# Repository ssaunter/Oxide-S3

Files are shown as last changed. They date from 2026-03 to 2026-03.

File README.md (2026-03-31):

# Oxide-S3
Oxide-S3 is a retro Spotify interface featuring a large TFT screen, a small OLED screen, 6 tactile switches, and 2 rotary encoders, all running on an ESP32-WROOM-1.

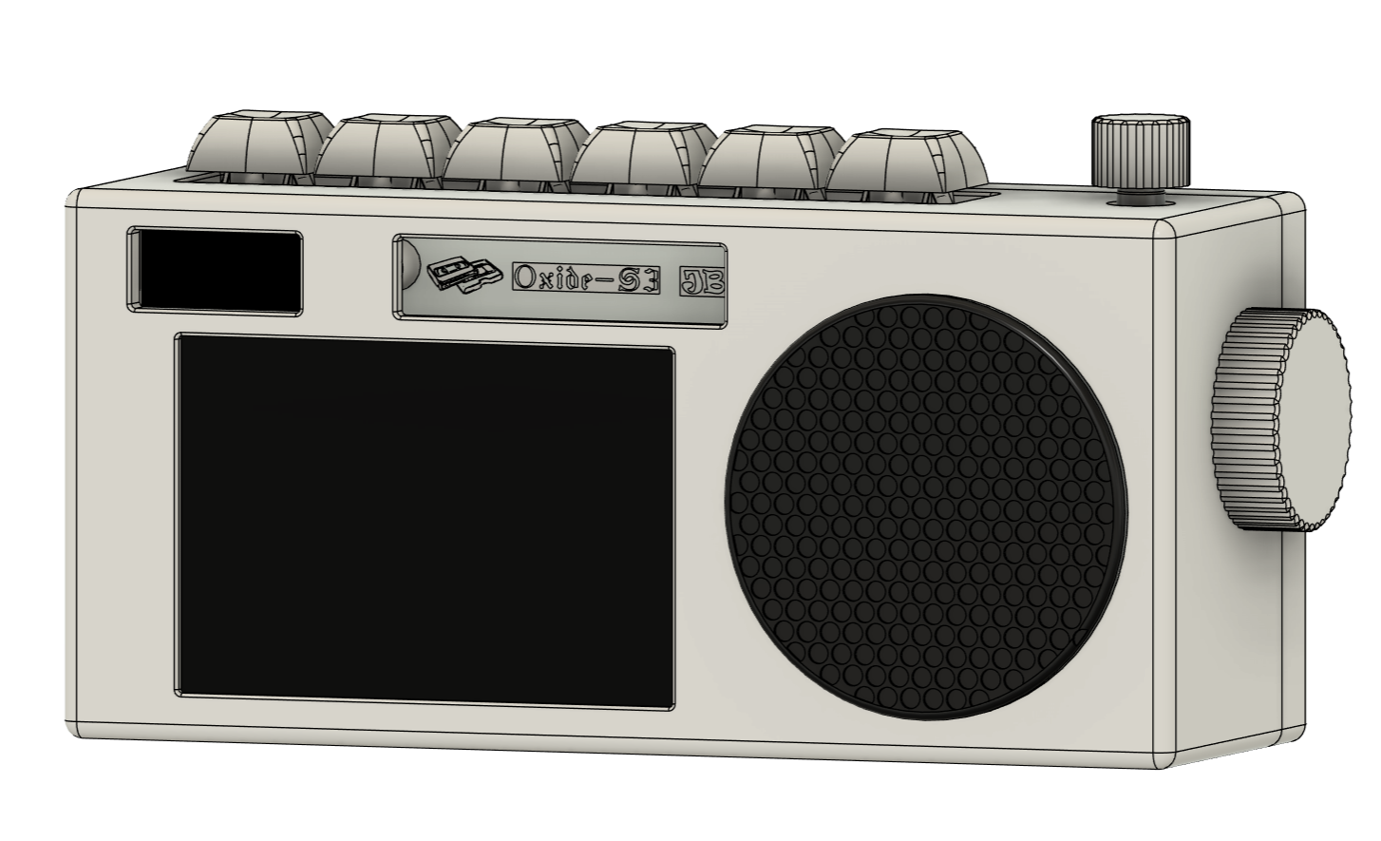
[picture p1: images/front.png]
Front Device


The device uses three seperate PCBs, one for the front, one for the top, and one for the side. The front PCB includes the displays, LiPo battery management, the MCU, and USB-C for charging. The top PCB includes the 6 Cherry MX Blue switches, and one of the rotary encoders. The side PCB simply includes the final rotary encoder. The small PCBs are connected to the front PCB using JST-XH cables.

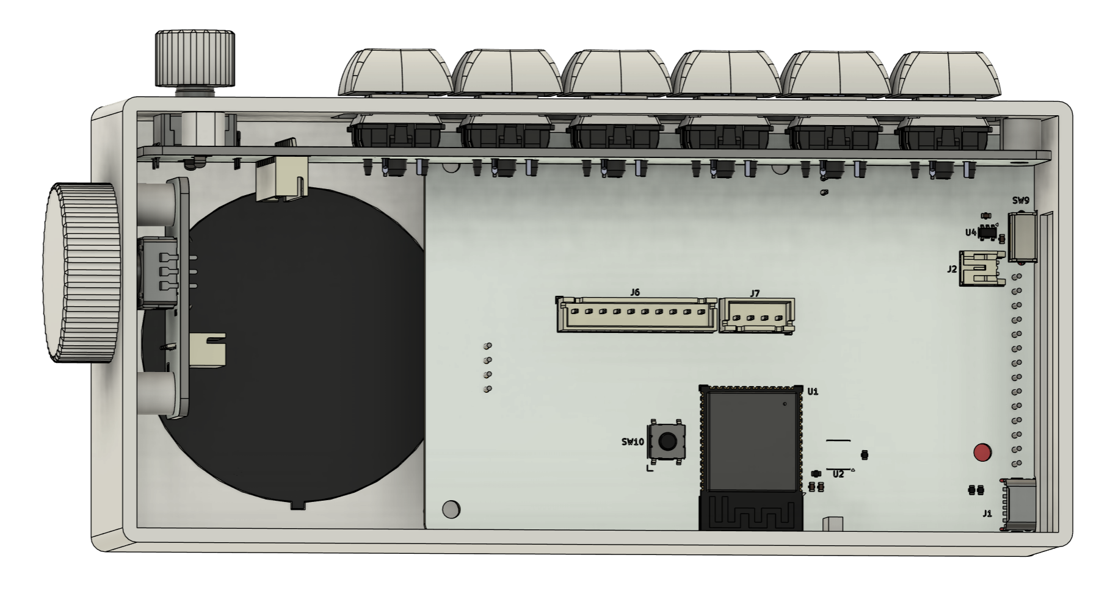
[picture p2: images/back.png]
Back Device


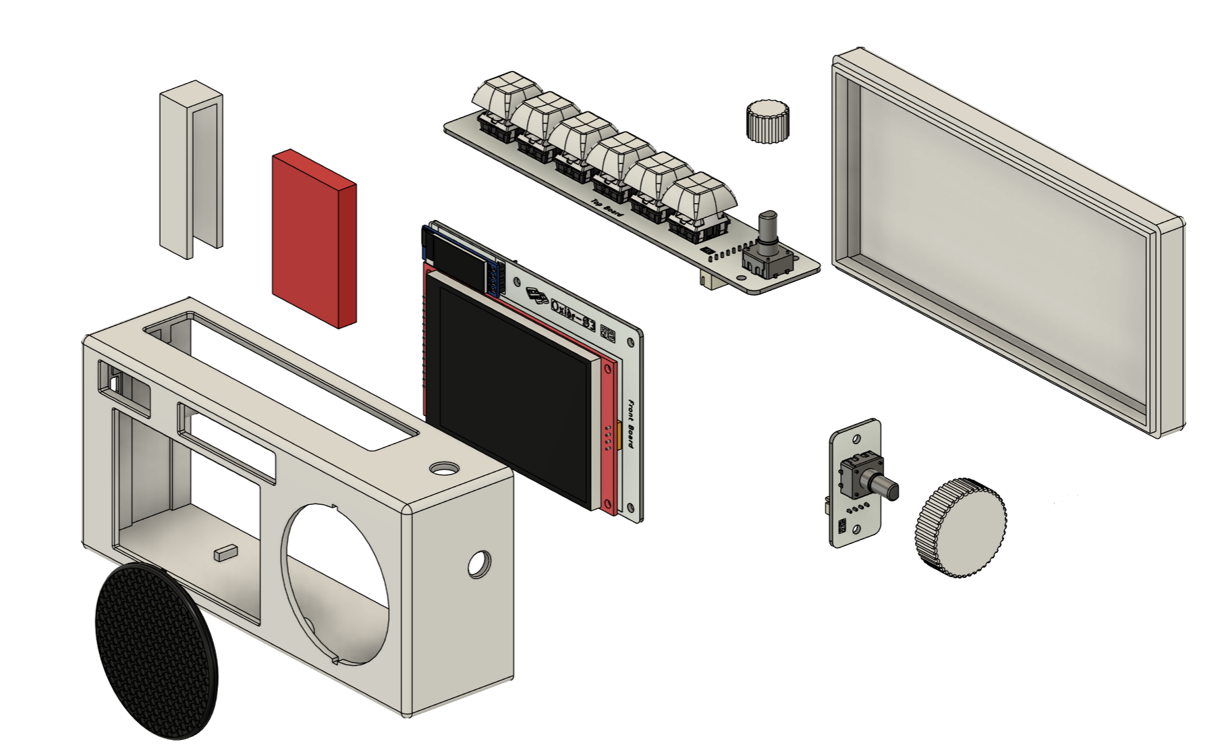
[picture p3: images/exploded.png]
Exploded View


# The PCBs

Front PCB:

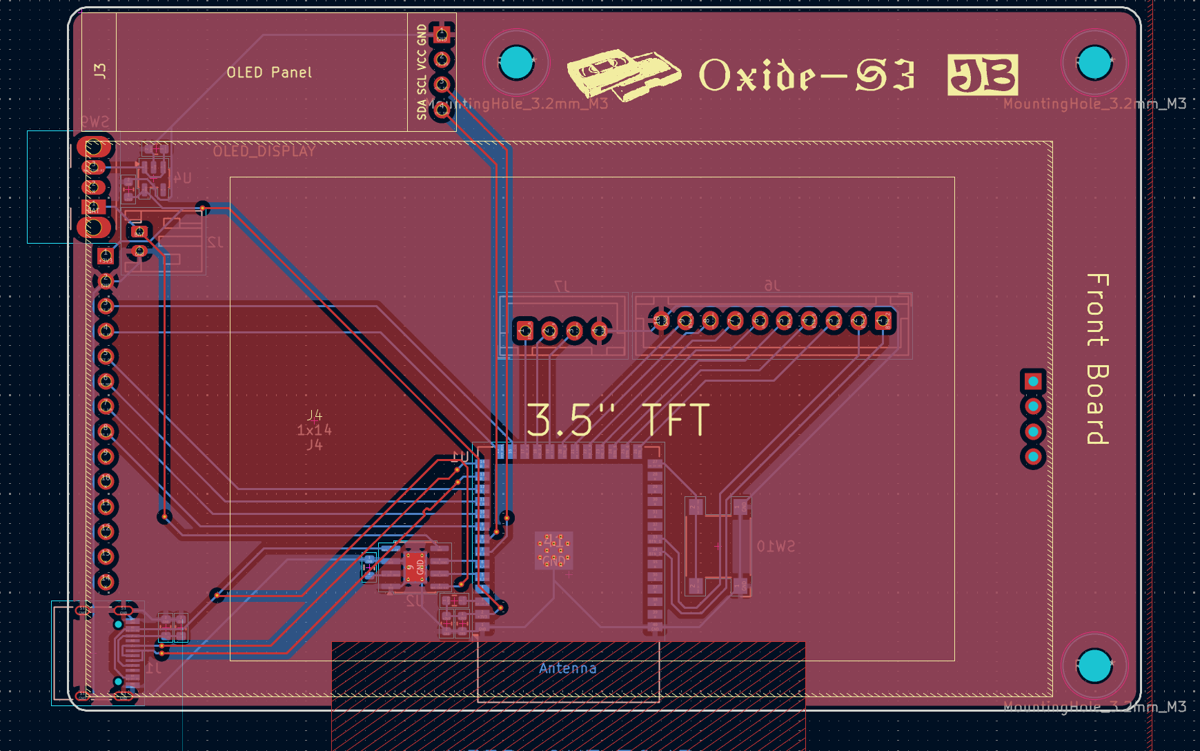
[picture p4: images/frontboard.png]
Front PCB


Top PCB:

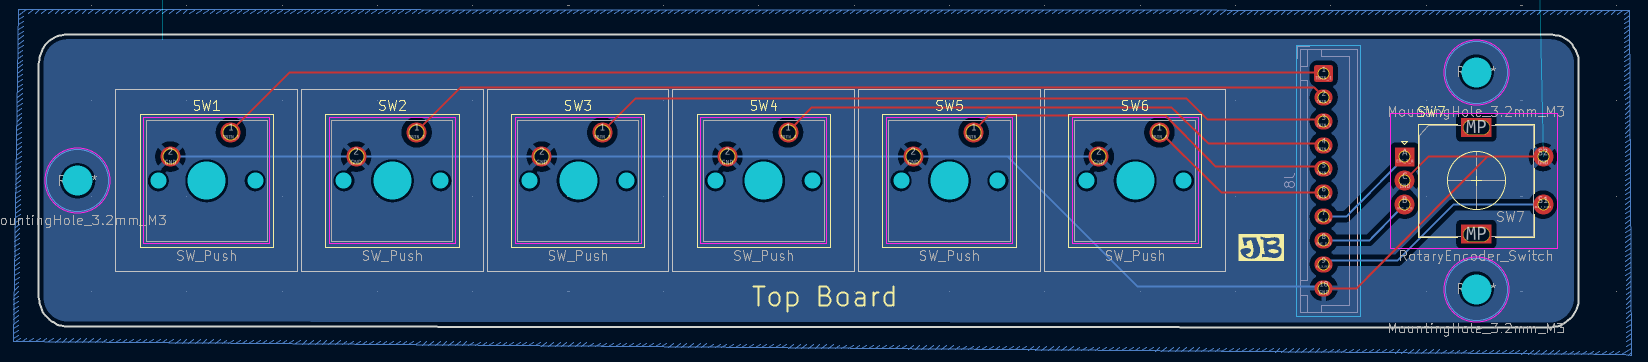
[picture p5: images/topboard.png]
Top PCB


Side PCB:

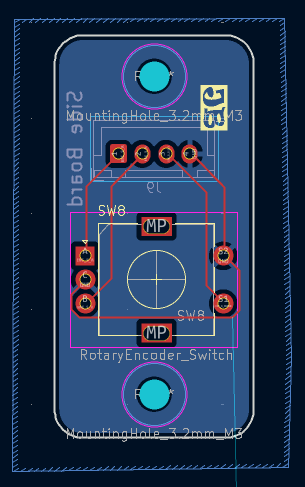
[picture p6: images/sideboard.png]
Side PCB


Schematic:

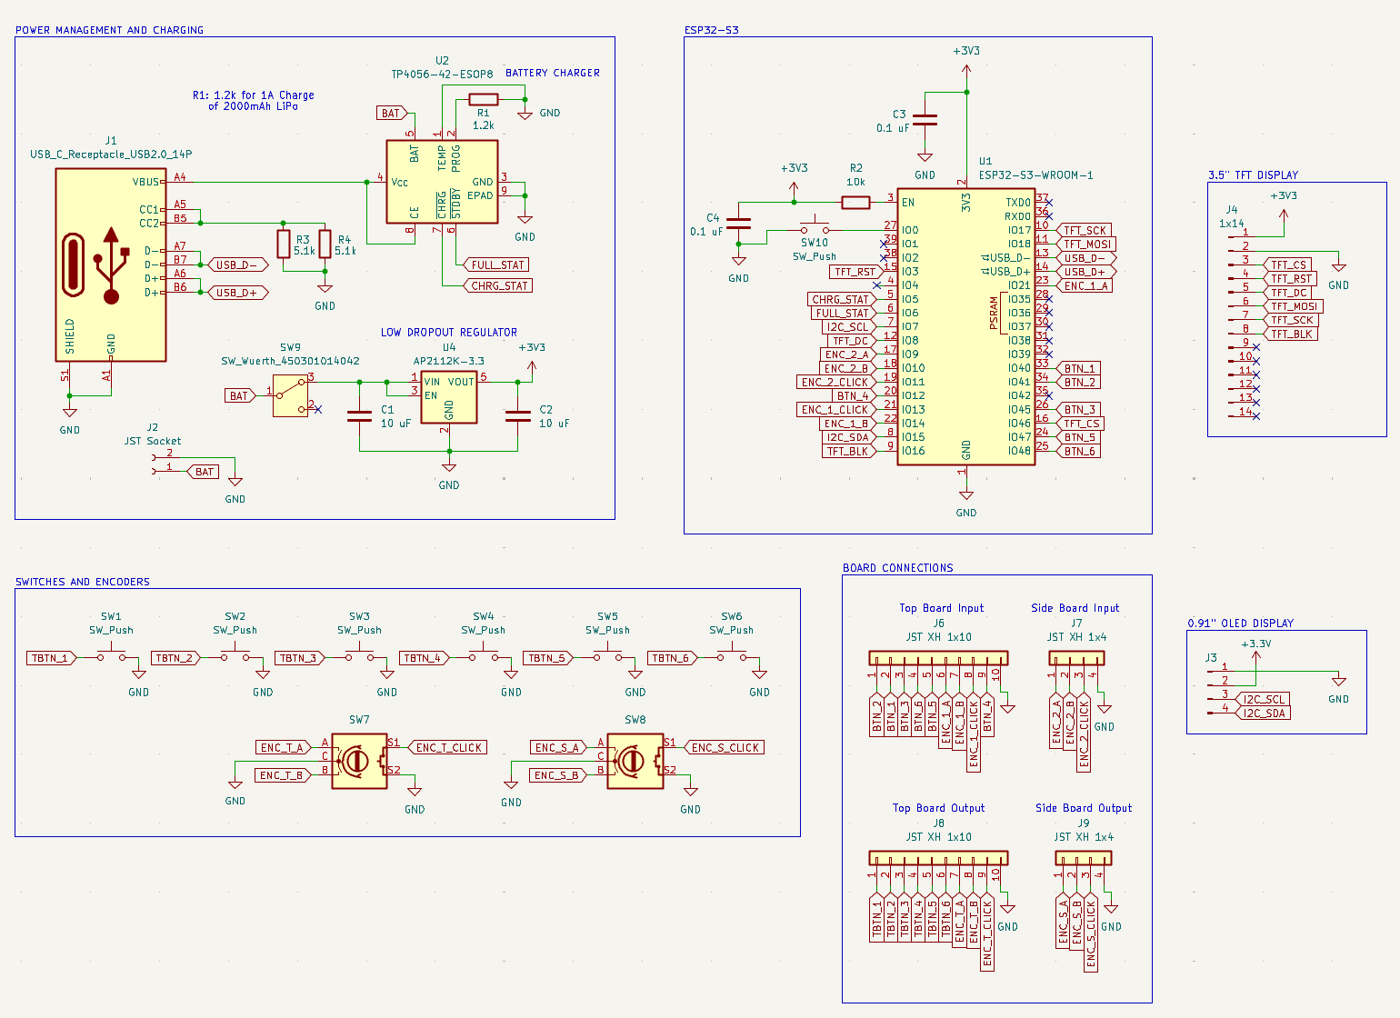
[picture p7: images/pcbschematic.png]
Schematic


# Assembly

The assembly is performed in several steps. First, 8 M3x5x5 threaded inserts are installed to the standoffs in the 3D printed front case. Then, the three PCBs are secured using M3x6 bolts.

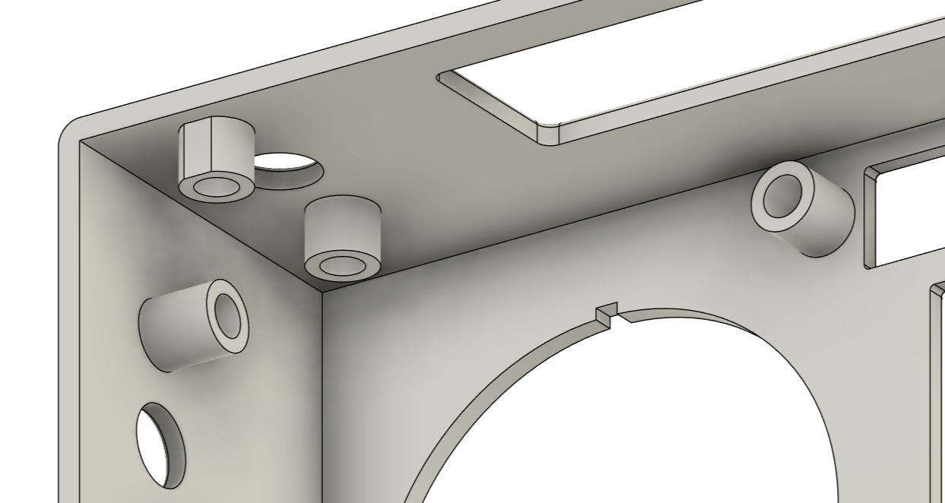
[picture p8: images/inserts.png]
Standoffs


 After the PCBs are installed, the battery holder module is press-fit into the front case, and the LiPo battery (red) is slid into place.

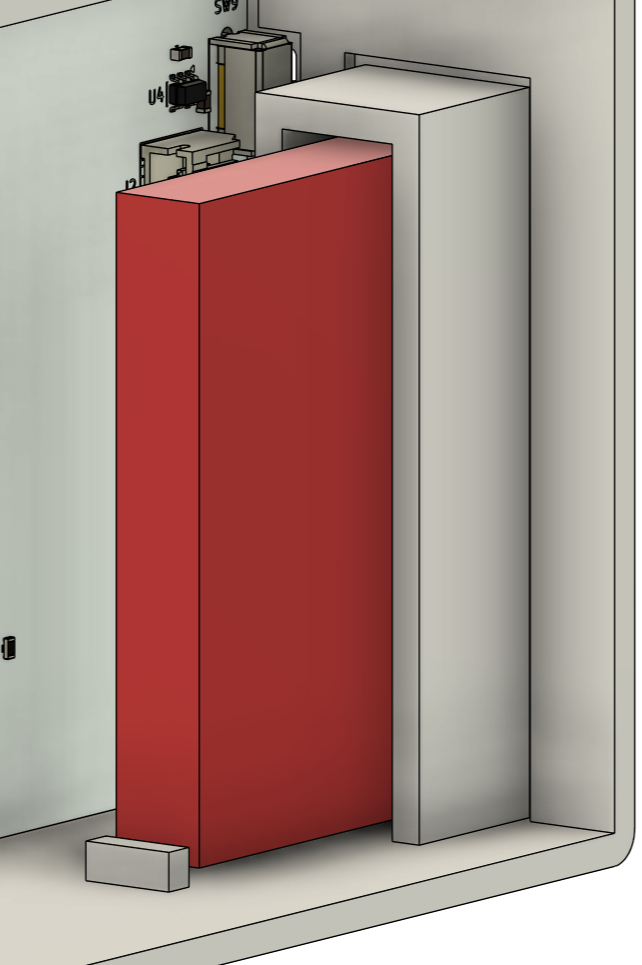
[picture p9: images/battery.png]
Battery


Then, the speaker and back case are press-fit into place. There is a 0.2mm tolerance built into the CAD model. 

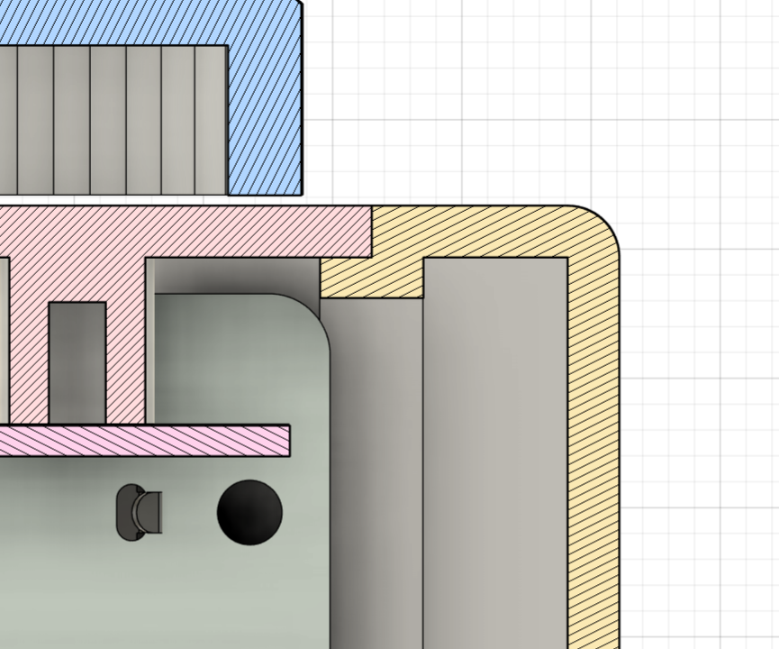
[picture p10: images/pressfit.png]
Press Fit


Finally, the side and top knob are  press-fit onto the rotary encoders. This concludes the assembly.

# Software

Taking inspiration from [Donatnan Jong](https://github.com/Dongathan-Jong), I plan to utilize Spotify's built-in [developer interface](https://developer.spotify.com/) and Adafruit display libraries to program the screens in the Arduino IDE. Since Wifi is easily handled by the ESP32 and the switches handled by Spotify's interface, the main focus would be on managing the displays. Given my short project turnaround time, I will update this repo once parts arrive.

The TFT screen will be controlled through SPI, and the OLED through I2C. To add images, I'll use a bitmap tool to add features. Below are the major functions of the two displays:

Required Libraries:
---
```
#include <Arduino.h>
#include <ArduinoJson.h>
#include <Adafruit_GFX.h>
#include <Adafruit_ST7735.h>
#include <WiFi.h>
#include <SpotifyEsp32.h>
#include <SPI.h>
```

|3.5" TFT|
| :---: |
|Spotify symbol|
|Song timestamp|
|Audio wave animation|
|Key switch/encoder map|
|Album navigation|
|Spotify username|

|0.91" OLED|
| :---: |
|Battery charge status|
|Clock|
|Volume/Mute symbol|
|Wifi status|

Like I mentioned, this project is super last minute (started less than a day ago). I'll write the code and update this repo once I recieve the parts, and show off what the Oxide-S3 can do. Here's an example of how simple the code can be, written by [Donatnan Jong](https://github.com/Dongathan-Jong/SpotifyDisplay/?tab=readme-ov-file):

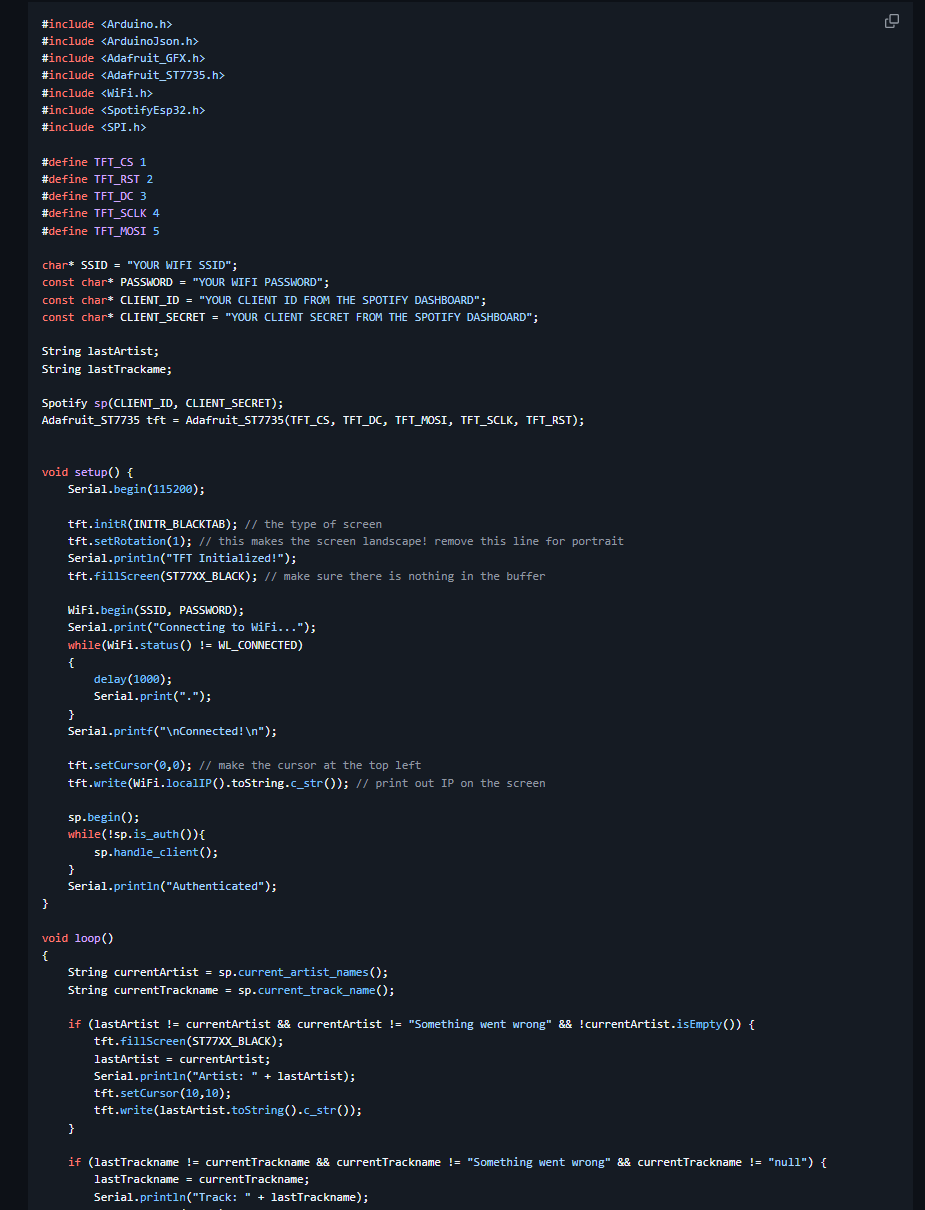
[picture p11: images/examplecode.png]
Example Code


# BOM

| Part | Quantity | Price Per | Link | 
| :--- | :---: | :---: | :--- |
| **0.91" OLED** | 1 | $1.95 | [AliExpress](https://www.aliexpress.us/item/3256806449757543.html) |
| **3.5" TFT** | 1 | $10.45 | [AliExpress](https://www.aliexpress.us/item/3256801812264108.html) |  
| **ESP32-S3-WROOM-1-N8R8** | 1 | $6.13 | [DigiKey](https://www.digikey.com/short/wq4p3rwv) |
| **LDO** | 1 | $0.22 | [DigiKey](https://www.digikey.com/short/b2m9hq2c) |
| **Battery Charger** | 1 | $0.47 | [DigiKey](https://www.digikey.com/short/dz9hbfw5) |
| **USB-C Recepticle** | 1 | $0.78 | [DigiKey](https://www.digikey.com/short/rnhfh9zp) |
| **Rotary Encoder** | 2 | $1.72 | [DigiKey](https://www.digikey.com/short/1mq4zdpt) |
| **Boot Button** | 1 | $0.56 |[DigiKey](https://www.digikey.com/short/q5bt28qt) |
| **Slide Switch** | 1 | $0.65 | [DigiKey](https://www.digikey.com/short/41mc094h) |
| **1x2 JST-PH** | 1 | $0.11 | [DigiKey](https://www.digikey.com/short/41b2w40z) |
| **1x10 JST-XH** | 2 | $0.32 |[DigiKey](https://www.digikey.com/short/5571c5z5) |
| **1x4 JST-XH** | 2 | $0.14 | [DigiKey](https://www.digikey.com/short/h5trn14w) |
| **1.2k R 0603** | 1 | $0.10 |[DigiKey](https://www.digikey.com/short/hnr0jfrp) |
| **5.1k R 0603** | 2 | $0.10 |[DigiKey](https://www.digikey.com/short/mmd3843z) |
| **10k R 0603** | 1 | $0.10 | [DigiKey](https://www.digikey.com/short/p59dnbn3) |
| **0.1uF C 0603** | 2 | $0.12 |[DigiKey](https://www.digikey.com.au/short/w83wjqbv) |
| **10uF C 0603** | 2 | $0.35 |[DigiKey](https://www.digikey.com/short/5dtppp4z) |
| **DSA Keycaps 10pcs** | 1 | (have) |[DigiKey](https://www.digikey.com/short/p4j0ztf5) |
| **Cherry MX Blue 10pcs** | 1 | $4.00 |[MechanicalKeyboards](https://mechanicalkeyboards.com/products/cherry-mx-blue-60g-clicky) |
| **1x10 JST-XH Jumper** | 1 | $3.40 |[AliExpress](https://www.aliexpress.us/item/3256807069159656.html) |
| **1x4 JST-XH Jumper** | 1 | $2.36 |[AliExpress](https://www.aliexpress.us/item/3256807069159656.html) |
| **1S 1500mAh LiPo** | 1 | (have) |[SparkFun](https://www.sparkfun.com/lithium-ion-battery-1500mah-iec62133-certified.html#content-documentation) |
| **MicroSD** | 1 | (have) | |
| **M3x6 Bolt** | 8 | (have) | |
| **M3x5x5 Threaded Insert** | 8 | (have) | |

Totals
---
| Service  | Price | 
| :--- | :--- |
| **JLCPCB Order** | $48.49 | |
| **DigiKey Order** | $32.36 | 
| **AliExpress Order** |  $19.44 | 
| **MechanicalKeyboards Order** |  $9.52 | 

This total comes out to $109.81 which is slightly over my limit. I'll downgrade to some generic Cherry MX Red switches, and some old DSA switches, both which I alreday have bringing the total to **$94.34**.

Orders:

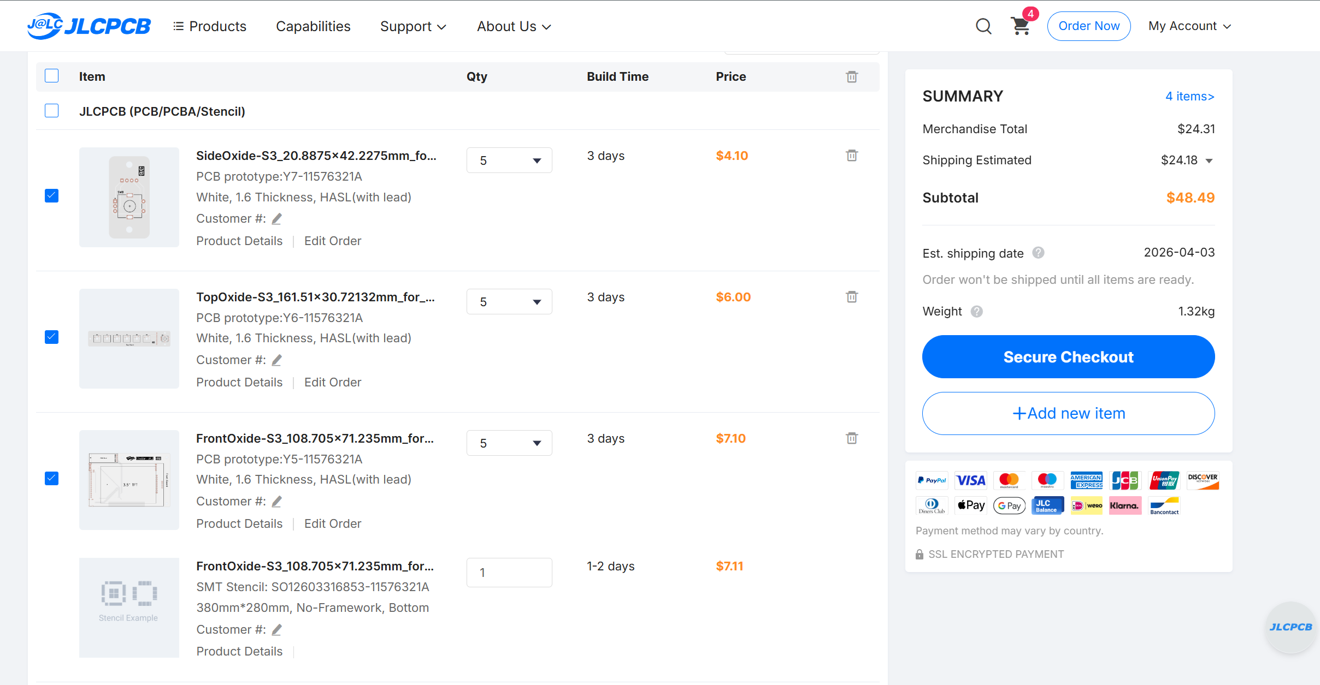
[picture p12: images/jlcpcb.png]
JLCPCB

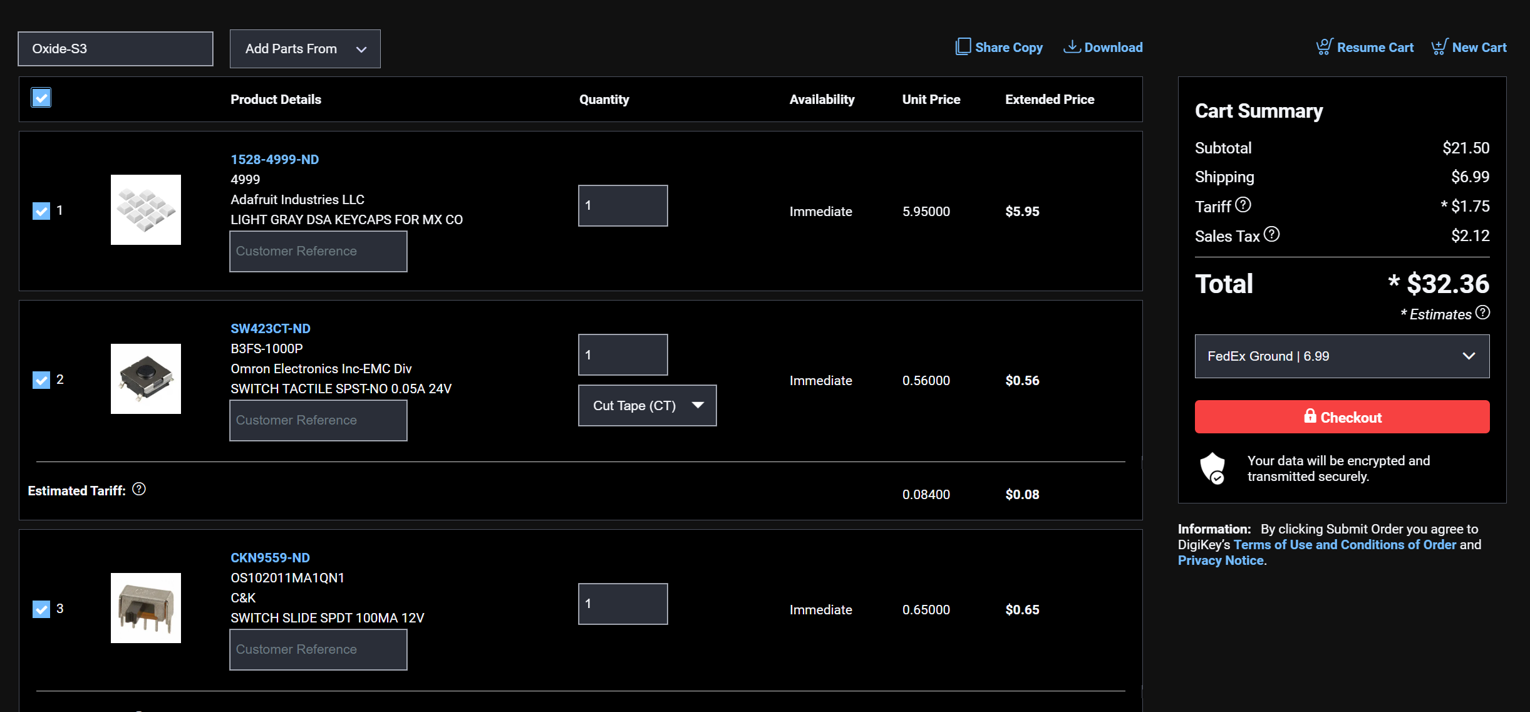
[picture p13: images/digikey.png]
Digikey

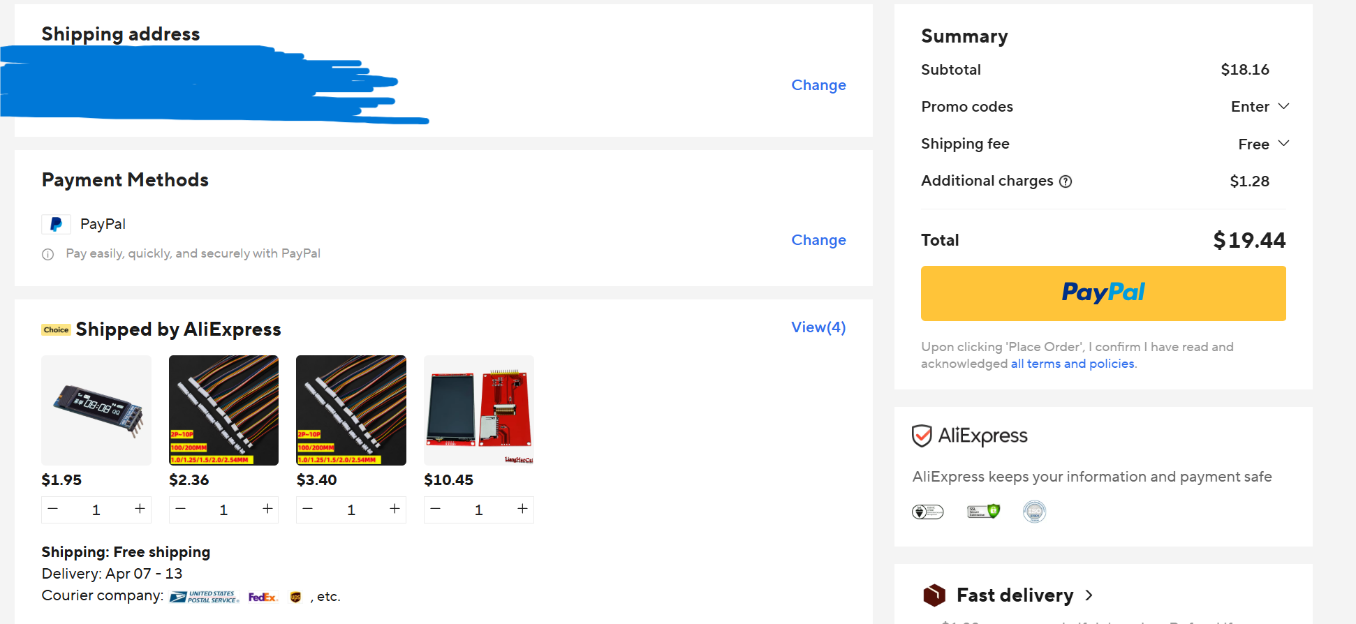
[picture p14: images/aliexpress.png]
AliExpress

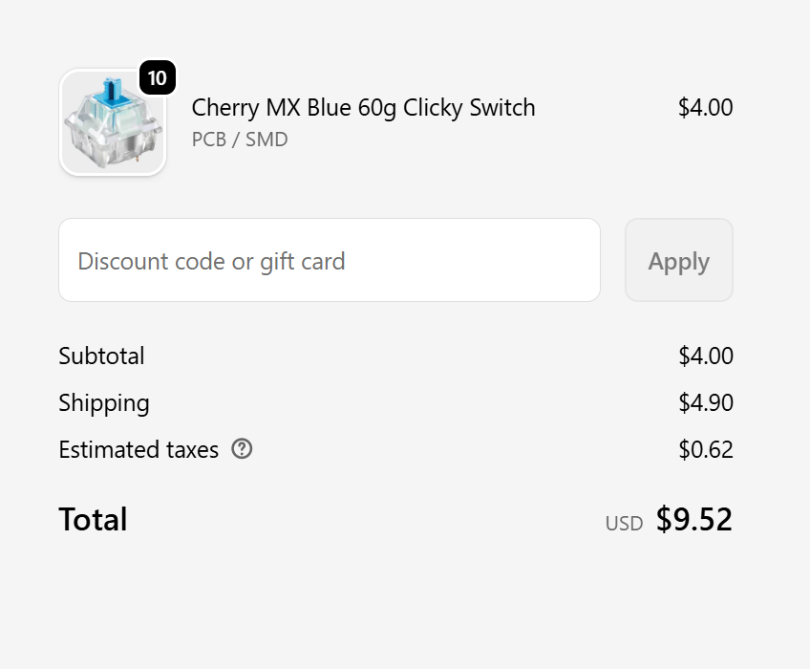
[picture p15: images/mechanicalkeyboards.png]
MechanicalKeyboards


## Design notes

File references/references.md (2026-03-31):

# Project References

[Dongathan-Jong Spotify Display](https://github.com/Dongathan-Jong/SpotifyDisplay/?tab=readme-ov-file)

Spotify Display

Old Radio

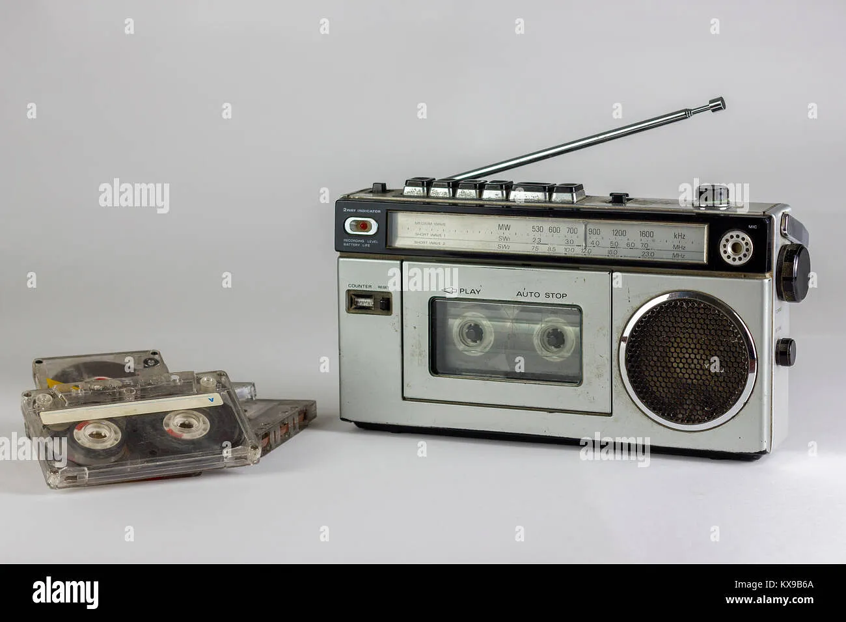
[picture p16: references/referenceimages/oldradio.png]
Old Radio


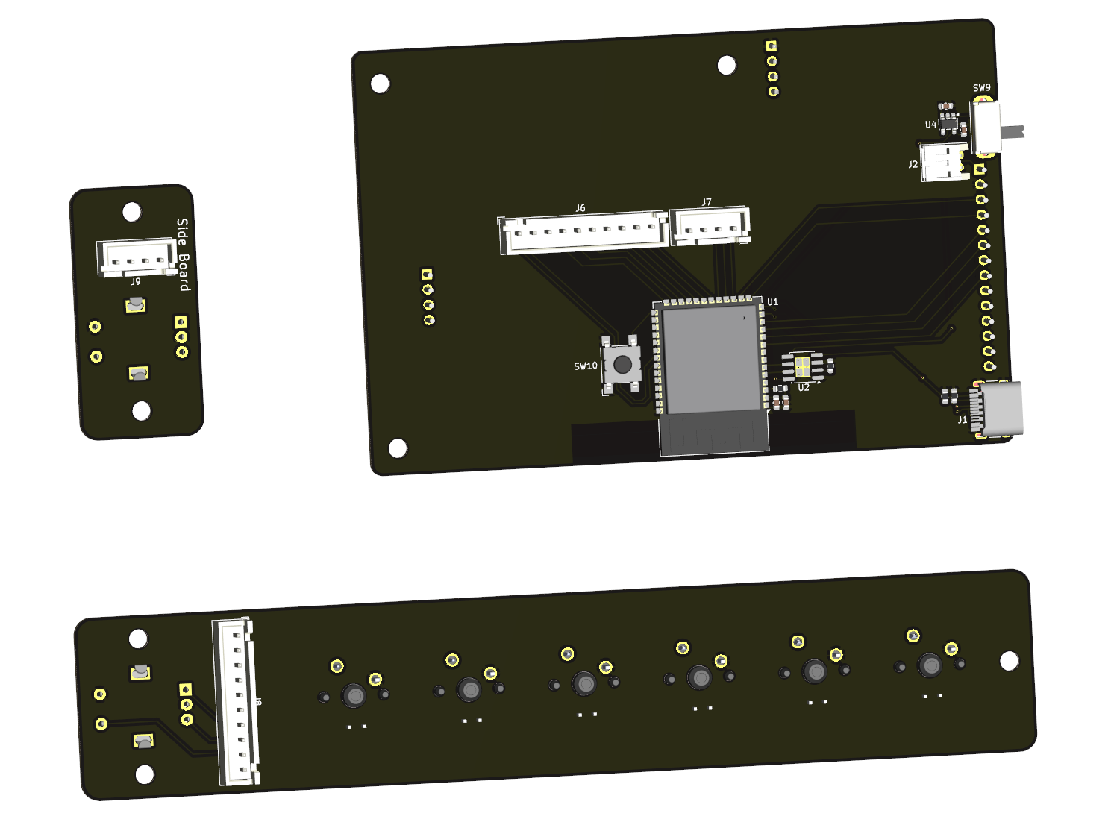
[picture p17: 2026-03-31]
images/3dpcbback.png

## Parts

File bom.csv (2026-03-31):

Part | Quantity | Price Per | Link
0.91-inch OLED | 1 | 1.95 | https://www.aliexpress.us/item/3256806449757543.html
3.5-inch TFT | 1 | 10.45 | https://www.aliexpress.us/item/3256801812264108.html
ESP32-S3-WROOM-1-N8R8 | 1 | 6.13 | https://www.digikey.com/short/wq4p3rwv
LDO | 1 | 0.22 | https://www.digikey.com/short/b2m9hq2c
Battery Charger | 1 | 0.47 | https://www.digikey.com/short/dz9hbfw5
USB-C Recepticle | 1 | 0.78 | https://www.digikey.com/short/rnhfh9zp
Rotary Encoder | 2 | 1.72 | https://www.digikey.com/short/1mq4zdpt
Boot Button | 1 | 0.56 | https://www.digikey.com/short/q5bt28qt
Slide Switch | 1 | 0.65 | https://www.digikey.com/short/41mc094h
1x2 JST-PH | 1 | 0.11 | https://www.digikey.com/short/41b2w40z
1x10 JST-XH | 2 | 0.32 | https://www.digikey.com/short/5571c5z5
1x4 JST-XH | 2 | 0.14 | https://www.digikey.com/short/h5trn14w
1.2k R 0603 | 1 | 0.10 | https://www.digikey.com/short/hnr0jfrp
5.1k R 0603 | 2 | 0.10 | https://www.digikey.com/short/mmd3843z
10k R 0603 | 1 | 0.10 | https://www.digikey.com/short/p59dnbn3
0.1uF C 0603 | 2 | 0.12 | https://www.digikey.com.au/short/w83wjqbv
10uF C 0603 | 2 | 0.35 | https://www.digikey.com/short/5dtppp4z
DSA Keycaps 10pcs | 1 | Handled | https://www.digikey.com/short/p4j0ztf5
1x10 JST-XH Jumper | 1 | 3.40 | https://www.aliexpress.us/item/3256807069159656.html
1x4 JST-XH Jumper | 1 | 2.36 | https://www.aliexpress.us/item/3256807069159656.html
1S 1500mAh LiPo | 1 | Handled | https://www.sparkfun.com/lithium-ion-battery-1500mah-iec62133-certified.html
MicroSD | 1 | Handled
M3x6 Bolt | 8 | Handled
M3x5x5 Threaded Insert | 8 | Handled
Generic MX Red Switches | 6 | Handled
Service | Price
JLCPCB Order | 48.49
DigiKey Order | 26.41
AliExpress Order | 19.44
TOTAL | 94.34

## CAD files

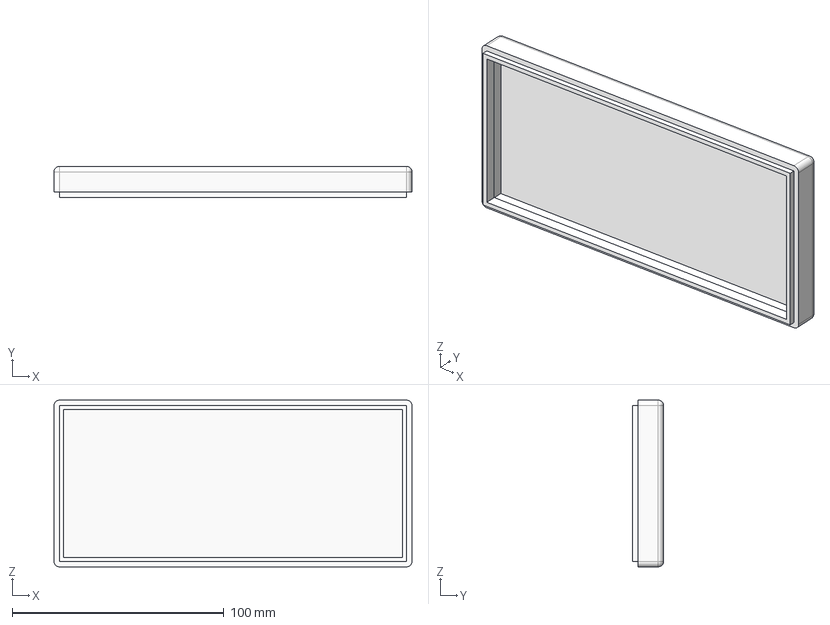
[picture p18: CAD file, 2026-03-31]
cad/Back Case.step
169.1 x 14.7 x 78.7 mm

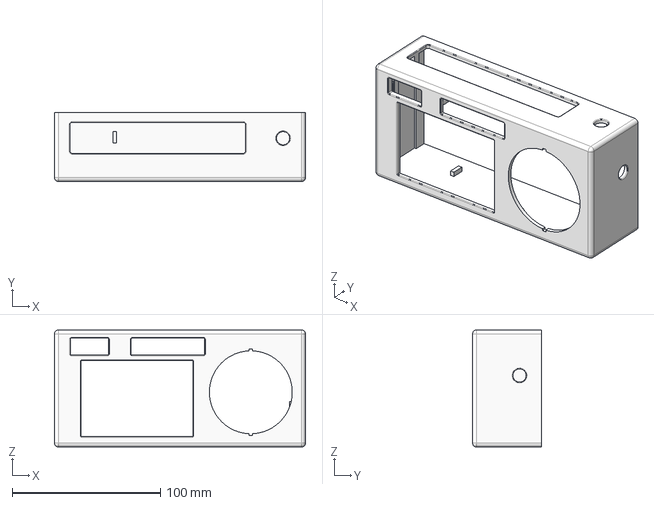
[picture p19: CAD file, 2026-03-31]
cad/Front Case.step
169.1 x 46.4 x 78.7 mm

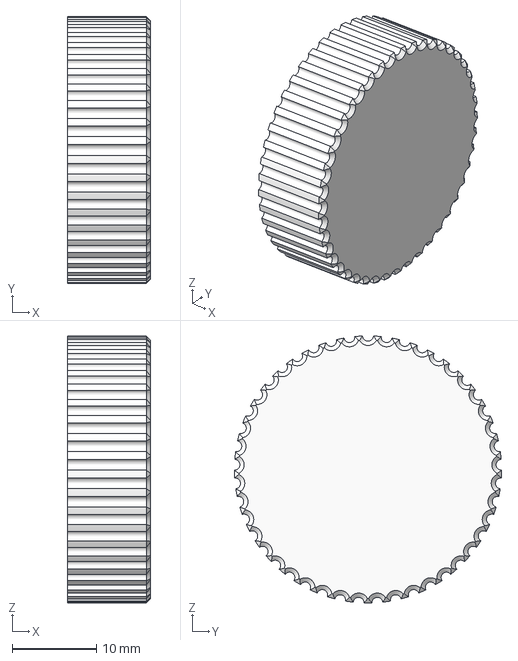
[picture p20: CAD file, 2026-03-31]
cad/Side Dial.step
9.91 x 31.7 x 31.7 mm

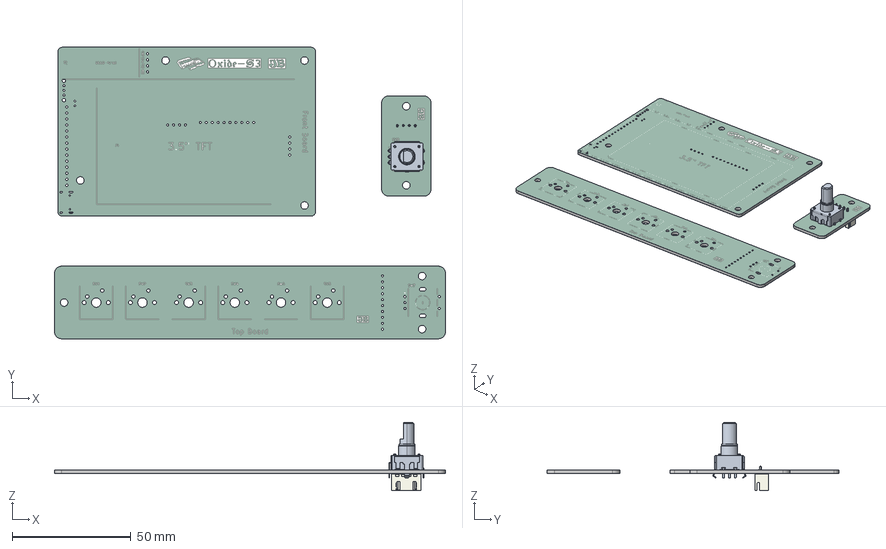
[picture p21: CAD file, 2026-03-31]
cad/Oxide-S3SIDE.step
164.8 x 122.9 x 28.7 mm
pec12r-4225f-s0024
JST_XH_B4B-XH-A_1x04_P2.50mm_Vertical
Oxide-S3_silkscreen x 2
Oxide-S3_soldermask x 2
Oxide-S3_PCB_1
Oxide-S3_PCB_2
Oxide-S3_PCB_3

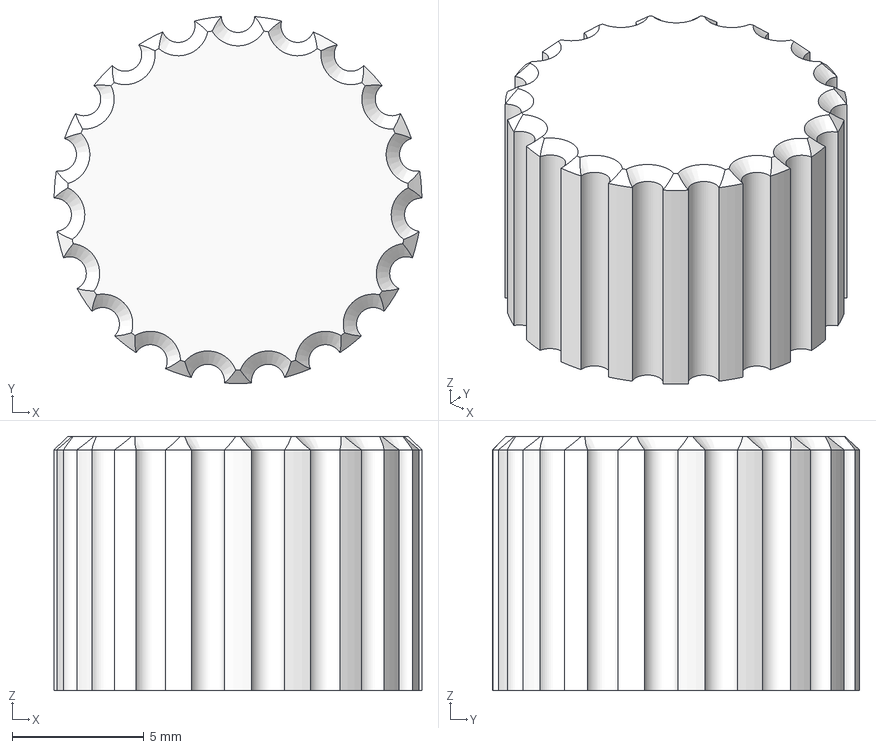
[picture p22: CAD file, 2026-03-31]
cad/Top Dial.step
14.0 x 13.9 x 9.65 mm

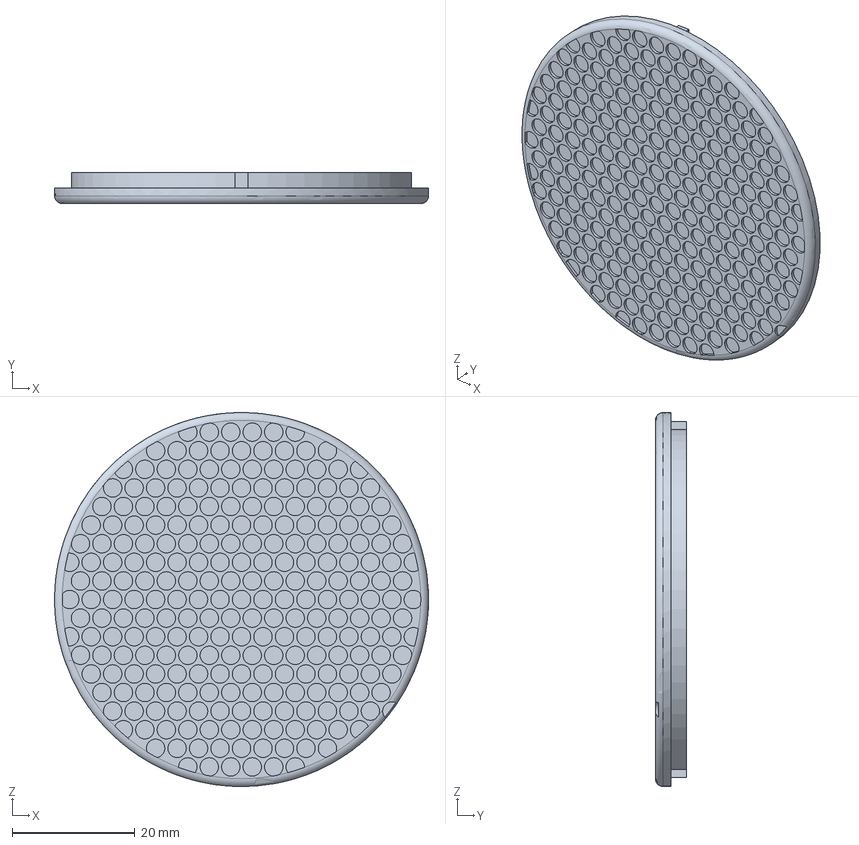
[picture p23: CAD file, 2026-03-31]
cad/Speaker Plate.step
60.9 x 5.08 x 61.0 mm

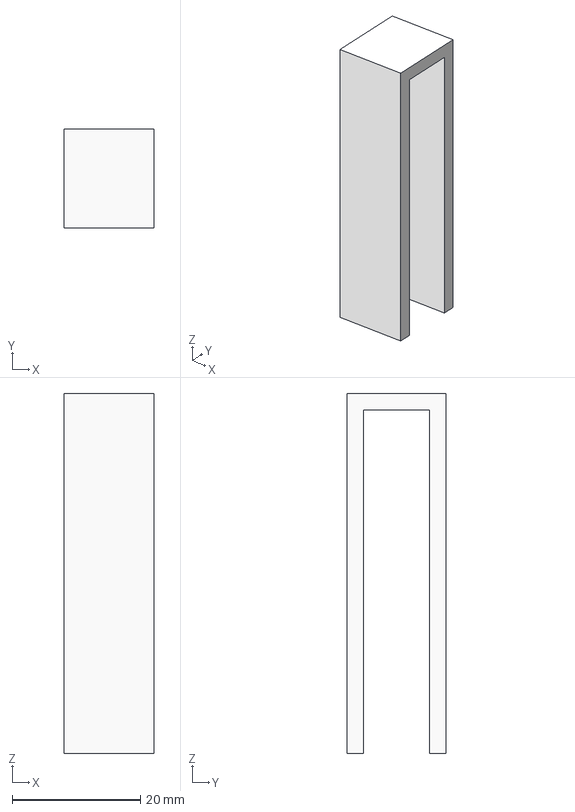
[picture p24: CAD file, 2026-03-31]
cad/Battery Holder.step
14.0 x 15.4 x 56.1 mm

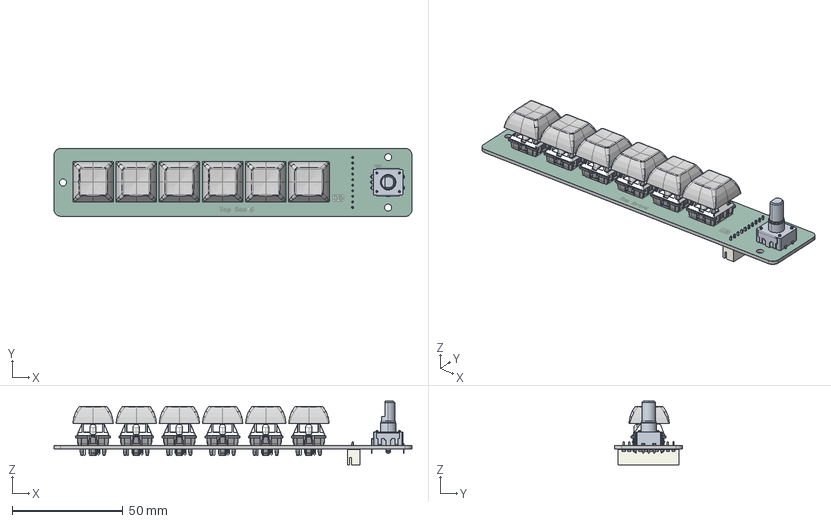
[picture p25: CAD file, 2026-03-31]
cad/Oxide-S3TOP.step
161.5 x 30.7 x 28.7 mm
Bottom x 6
Pulsador x 6
Top x 6
Pieza5^Cherry MX x 6
Pin1 x 6
Pin2 x 6
Led 3mm_trans x 6
DSA_Keycap_CherryMX x 6
pec12r-4225f-s0024
JST_XH_B10B-XH-A_1x10_P2.50mm_Vertical
Oxide-S3_silkscreen x 2
Oxide-S3_soldermask x 2
Oxide-S3_PCB

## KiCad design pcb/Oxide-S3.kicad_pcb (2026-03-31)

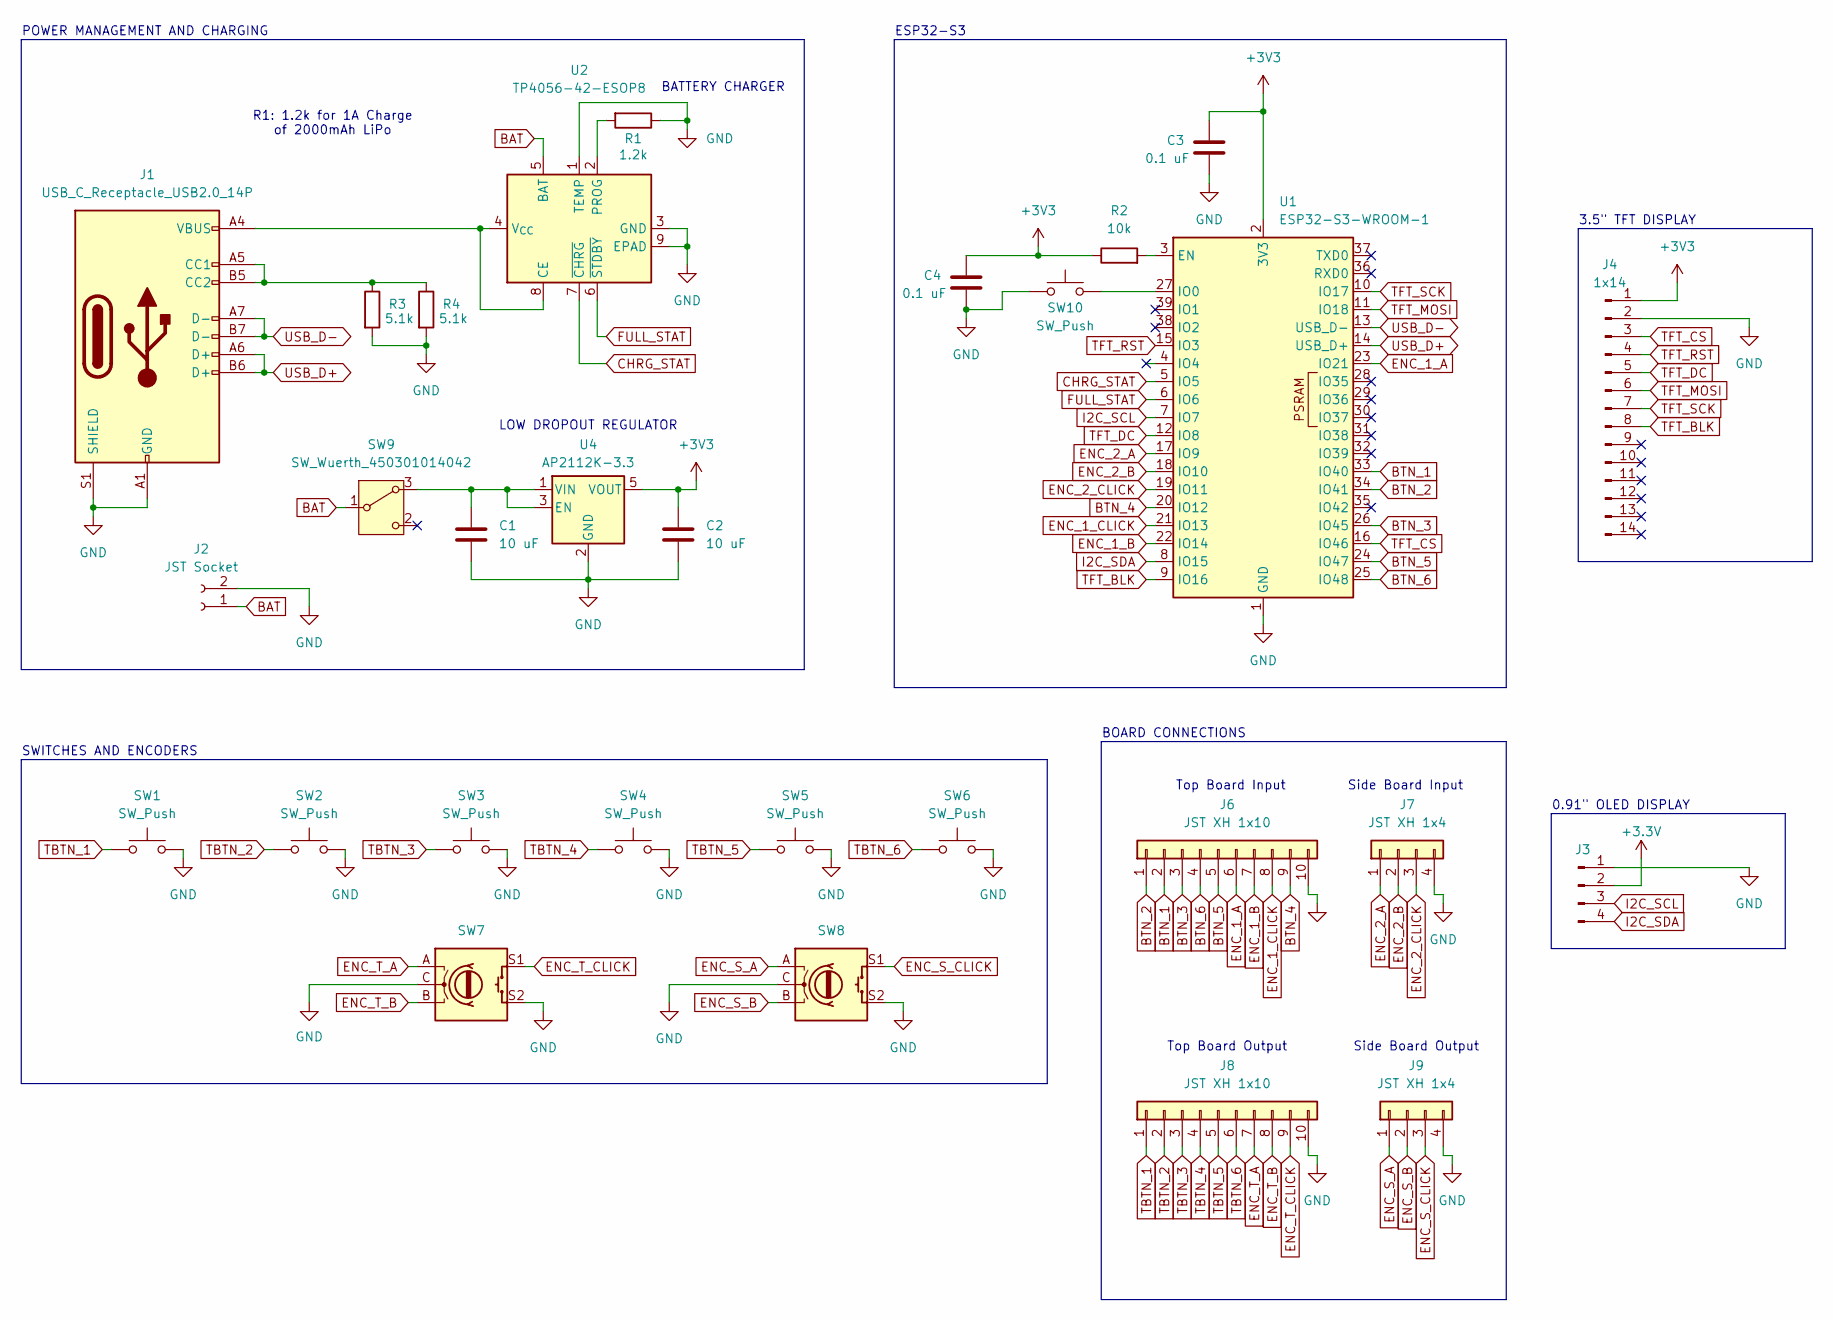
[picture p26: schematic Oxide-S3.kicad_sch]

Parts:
C1, C2: 10 uF; C_0603_1608Metric
C3, C4: 0.1 uF; C_0603_1608Metric
J1: USB_C_Receptacle_USB2.0_14P; USB_C_Receptacle_HRO_TYPE-C-31-M-12
J2: JST Socket; JST_PH_S2B-PH-K_1x02_P2.00mm_Horizontal
J3: OLED_DISPLAY; SSD1306-0.91-OLED-4pin-128x32
J4: 1x14; 3.5_TFT_Screen
J6, J8: JST XH 1x10; JST_XH_B10B-XH-A_1x10_P2.50mm_Vertical
J7, J9: JST XH 1x4; JST_XH_B4B-XH-A_1x04_P2.50mm_Vertical
R1: 1.2k; R_0603_1608Metric
R2: 10k; R_0603_1608Metric
R3, R4: 5.1k; R_0603_1608Metric
SW1, SW2, SW3, SW4, SW5, SW6: SW_Push; SW_Cherry_MX_1.00u_PCB
SW7, SW8: RotaryEncoder_Switch; RotaryEncoder_Alps_EC11E-Switch_Vertical_H20mm
SW9: SW_Wuerth_450301014042; SW_Slide_SPDT_Angled_CK_OS102011MA1Q
SW10: SW_Push; SW_SPST_Omron_B3FS-100xP
U1: ESP32-S3-WROOM-1
U2: TP4056-42-ESOP8; SOIC-8-1EP_3.9x4.9mm_P1.27mm_EP2.41x3.3mm_ThermalVias
U4: AP2112K-3.3; SOT-23-5

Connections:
+3.3V: J3.2
+3V3: C2.1, C3.1, C4.1, J4.1, R2.1, U1.2 (3V3), U4.5 (VOUT)
BAT: J2.1, SW9.1 (B), U2.5 (BAT)
BTN_1: J6.2, U1.33 (IO40)
BTN_2: J6.1, U1.34 (IO41)
BTN_3: J6.3, U1.26 (IO45)
BTN_4: J6.9, U1.20 (IO12)
BTN_5: J6.5, U1.24 (IO47)
BTN_6: J6.4, U1.25 (IO48)
CHRG_STAT: U1.5 (IO5), U2.7 (~CHRG)
ENC_1_A: J6.6, U1.23 (IO21)
ENC_1_B: J6.7, U1.22 (IO14)
ENC_1_CLICK: J6.8, U1.21 (IO13)
ENC_2_A: J7.1, U1.17 (IO9)
ENC_2_B: J7.2, U1.18 (IO10)
ENC_2_CLICK: J7.3, U1.19 (IO11)
ENC_S_A: J9.1, SW8.A
ENC_S_B: J9.2, SW8.B
ENC_S_CLICK: J9.3, SW8.S1
ENC_T_A: J8.7, SW7.A
ENC_T_B: J8.8, SW7.B
ENC_T_CLICK: J8.9, SW7.S1
FULL_STAT: U1.6 (IO6), U2.6 (~STDBY)
GND: C1.2, C2.2, C3.2, C4.2, J1.A1 (GND), J1.A12 (GND), J1.B1 (GND), J1.B12 (GND), J1.S1 (SHIELD), J2.2, J3.1, J4.2, J6.10, J7.4, J8.10, J9.4, R1.1, R3.2, R4.2, SW1.2, SW2.2, SW3.2, SW4.2, SW5.2, SW6.2, SW7.C, SW7.S2, SW8.C, SW8.S2, SW10.1, U1.1 (GND), U1.40 (GND), U1.41 (GND), U2.1 (TEMP), U2.3 (GND), U2.9 (EPAD), U4.2 (GND)
I2C_SCL: J3.3, U1.7 (IO7)
I2C_SDA: J3.4, U1.8 (IO15)
unnamed: J1.A5 (CC1), J1.B5 (CC2), R3.1, R4.1
unnamed: C1.1, SW9.3 (A), U4.1 (VIN), U4.3 (EN)
unnamed: R2.2, U1.3 (EN)
unnamed: SW10.2, U1.27 (IO0)
unnamed: J1.A4 (VBUS), J1.A9 (VBUS), J1.B4 (VBUS), J1.B9 (VBUS), U2.4 (V_{CC}), U2.8 (CE)
unnamed: R1.2, U2.2 (PROG)
TBTN_1: J8.1, SW1.1
TBTN_2: J8.2, SW2.1
TBTN_3: J8.3, SW3.1
TBTN_4: J8.4, SW4.1
TBTN_5: J8.5, SW5.1
TBTN_6: J8.6, SW6.1
TFT_BLK: J4.8, U1.9 (IO16)
TFT_CS: J4.3, U1.16 (IO46)
TFT_DC: J4.5, U1.12 (IO8)
TFT_MOSI: J4.6, U1.11 (IO18)
TFT_RST: J4.4, U1.15 (IO3)
TFT_SCK: J4.7, U1.10 (IO17)
USB_D+: J1.A6 (D+), J1.B6 (D+), U1.14 (USB_D+)
USB_D-: J1.A7 (D-), J1.B7 (D-), U1.13 (USB_D-)

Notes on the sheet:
ESP32-S3
Side Board Output
3.5" TFT DISPLAY
0.91" OLED DISPLAY
BATTERY CHARGER
POWER MANAGEMENT AND CHARGING
Top Board Input
Side Board Input
Top Board Output
BOARD CONNECTIONS
R1: 1.2k for 1A Charge of 2000mAh LiPo
LOW DROPOUT REGULATOR
SWITCHES AND ENCODERS

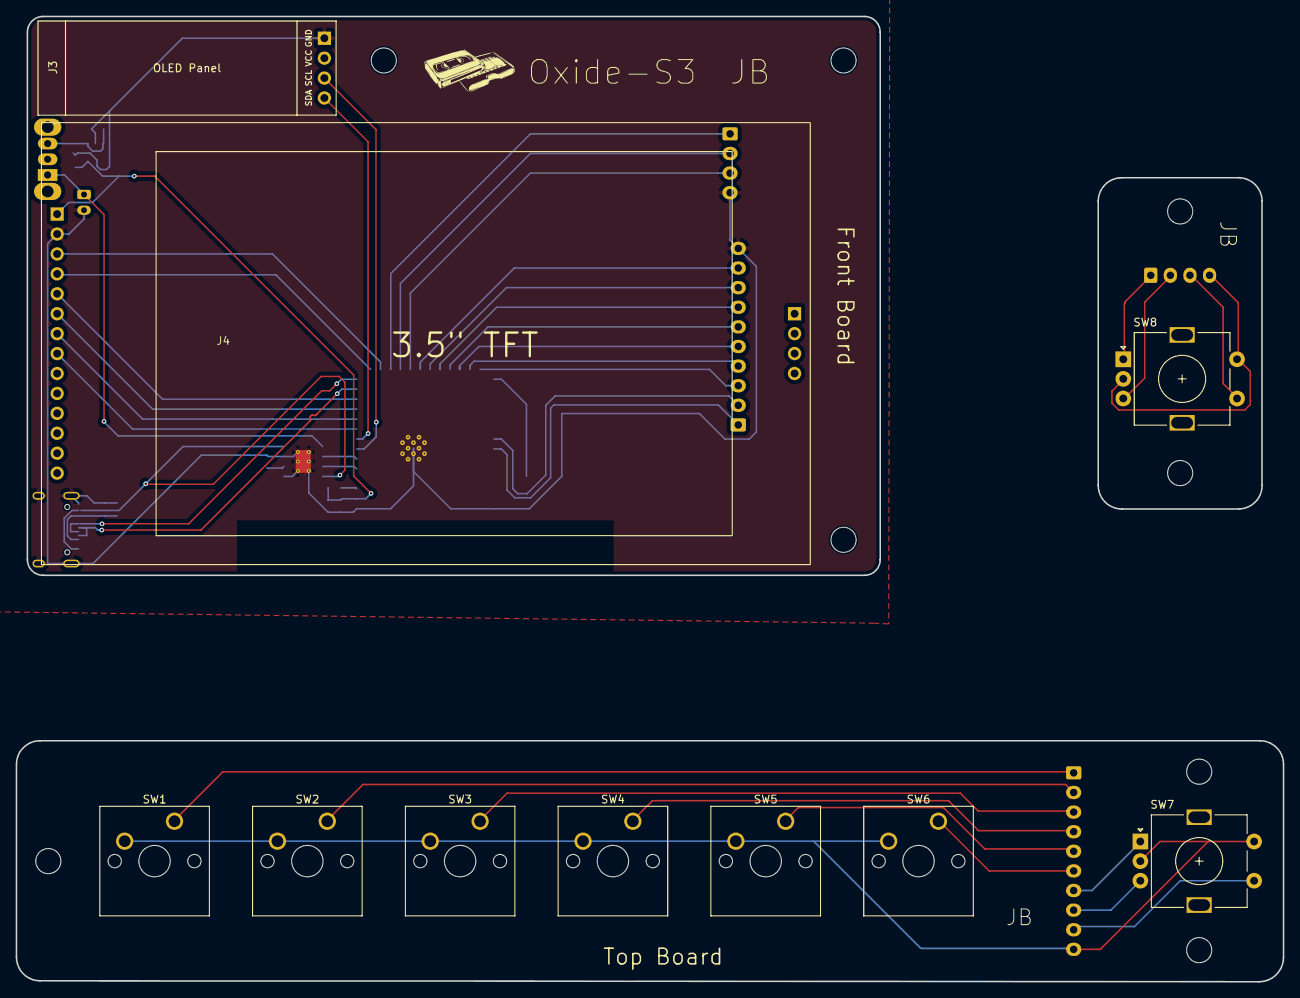
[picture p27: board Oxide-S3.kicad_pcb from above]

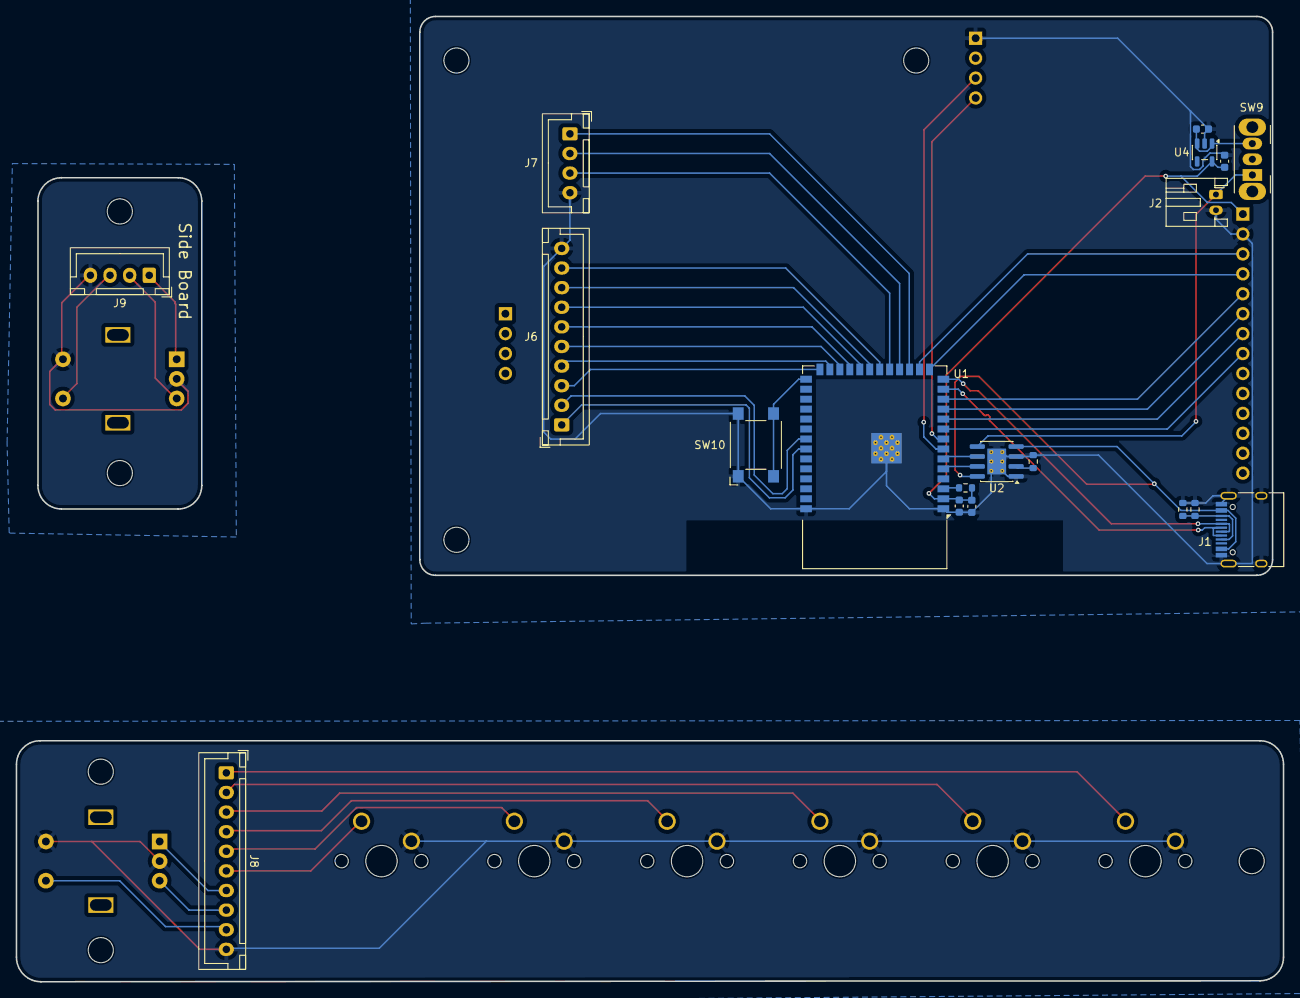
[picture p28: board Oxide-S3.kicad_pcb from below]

Board: 2 copper layers, 161.5 x 123.0 mm, 29 parts (19 on the bottom side), 45 nets.

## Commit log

2026-03-31 main commit
    added everything
    [Back Case.step, Battery Holder.step, Front Case.step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]
2026-03-31 updated bom
    [bom.csv]
2026-03-31 fixed csv
    [bom.csv]
2026-03-31 updated csv
    [bom.csv]
2026-03-31 added full cad and updated readme
